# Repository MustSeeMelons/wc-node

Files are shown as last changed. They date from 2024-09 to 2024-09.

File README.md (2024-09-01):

# WC internet radio

Inspired by a restroom that welcomed me as I entered, played smooth jazz while I was inside, and even said goodbye as I left. A Raspberry Pi Zero W at the heart.

All audio playback is based on [this Adafruit article](https://learn.adafruit.com/adafruit-max98357-i2s-class-d-mono-amp/raspberry-pi-wiring).

Legacy 32-bit Pi OS is required for this to work.

## V1

Turns out using a sonar distance sensor for presence detection does not work very well. You might enter the room and stay out of range for a bit, thus triggering a leave. Then after a bit re-trigger it. Many edge cases, for proper operation switch should be on the door and the door must be auto-closing. Otherwise the user experience will be flawed.

Kept the sonar as the on/off switch. Made to just work without spending much time on the looks.

Consists of a Pi Zero W, MAX98357 and a HC-SR04. Everything is powored from the Pi. Suprisingly, sounds better than most laptops.

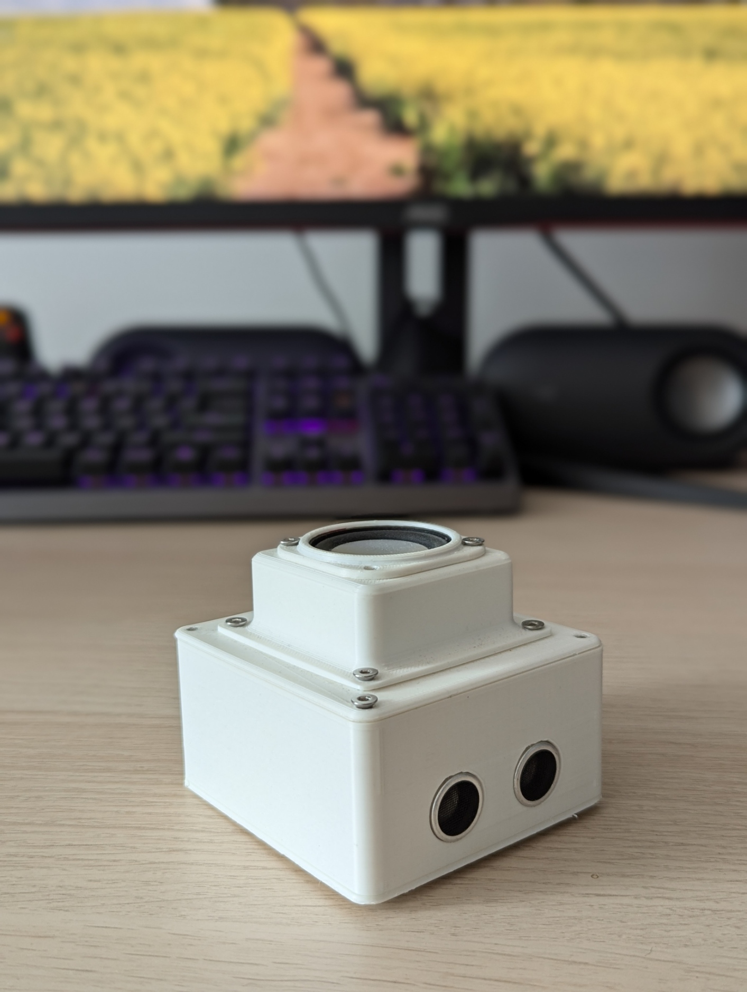
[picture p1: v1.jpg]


## V2

While the V1 worked well, it did not look the part. Also the sonar was a gimmick and it lacked physical volume controls that turned out more important than anticipated.

The sonar was replaced with a switch and a rotary encoder entered the fray. Turn it on/off with the switch and adjust the volume with the ring around the speaker.

Worked well enough, but it sounded worse. Propably because the speaker was not as enclosed as it was previsouly. The ring was also flimsy feeling. For some reason I used a rotary encoder from a mouse. Which is tiny and made positioning it harder. Also bearings would have been nice.

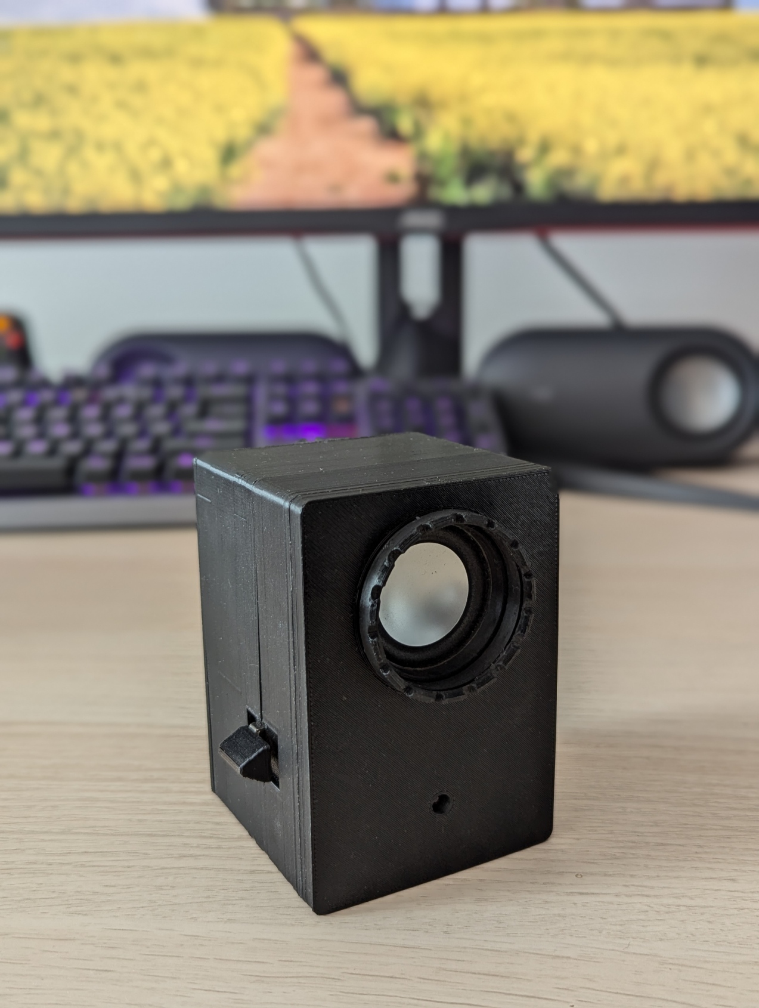
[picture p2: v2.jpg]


## V3

Time to make it louder and make it look even nicer. Made possible by a bunch of interconencted modules: 12V power to an Aliexpress amplifirer. Buck/boost module to step down 12V to 5V for the Pi. An PCM5102A module for turning the Pi's I2S signal into analogue audio. Non removable 12V power brick.

Operation requires pressing a button to turn on audio playback from the Pi and turning nob to turn off the amp and perform volume control.

Sounds better and overall is much more pleasing to the eye.

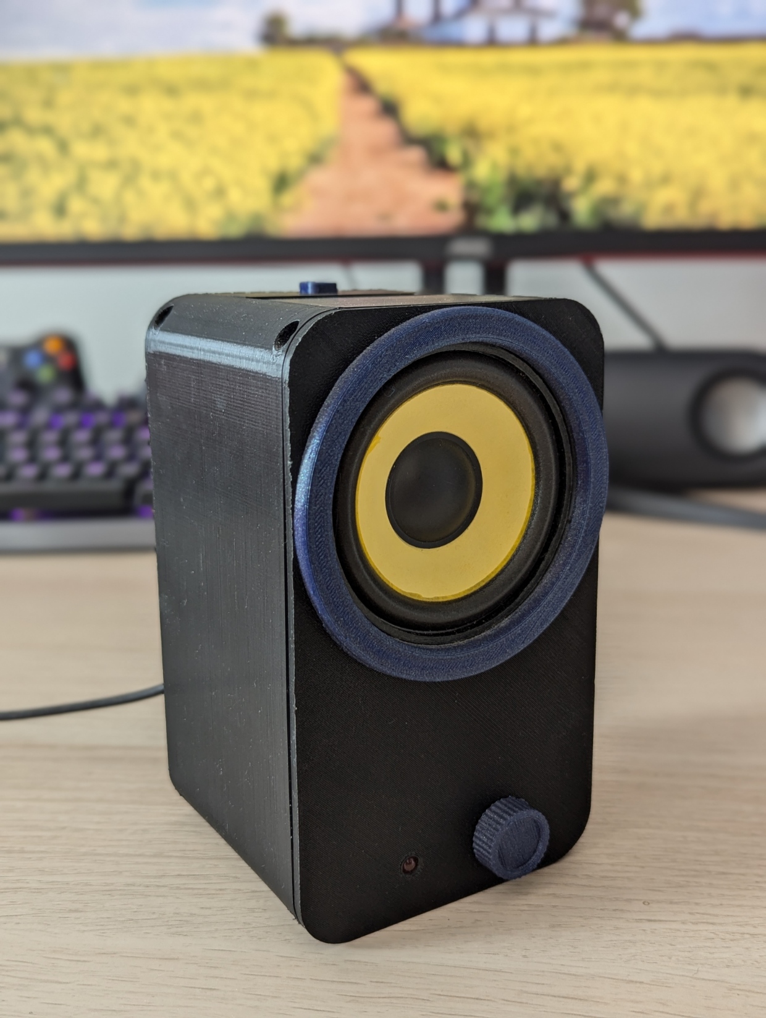
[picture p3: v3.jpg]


## V4

The final iteration: getting rid of the rats nest of modules and making an integrated PCB for all. About 1.5 years of learning electronics made it possible.

It works better as ever and propably is the final form.

Is it perfect? Hell no, but functional without major flaws as far as I know. The PCB layouts ignore `recomended layouts` from the datasheets so to be easier to hand solder.

The speaker size really should be placed into a wooded enclosure. Also the [stream](https://fmstream.org/) quality is a factor now.

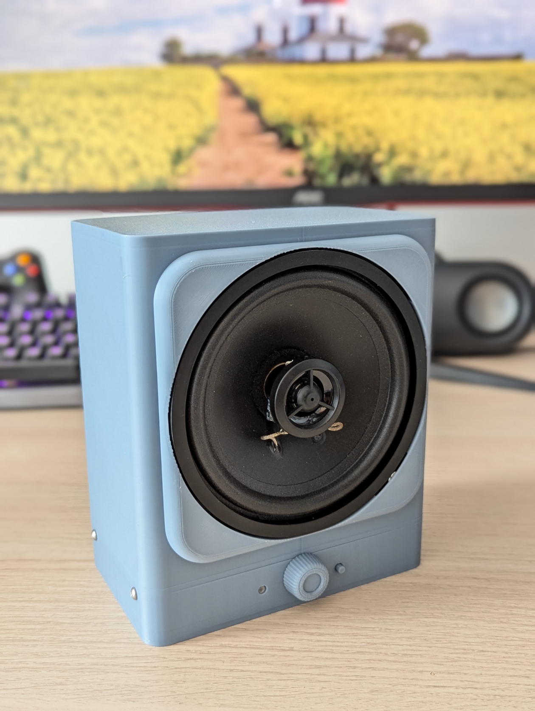
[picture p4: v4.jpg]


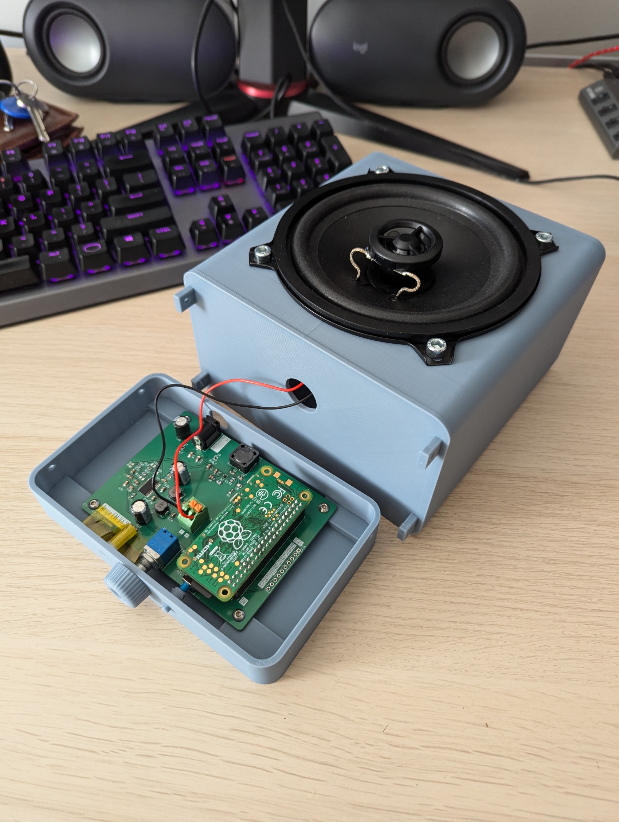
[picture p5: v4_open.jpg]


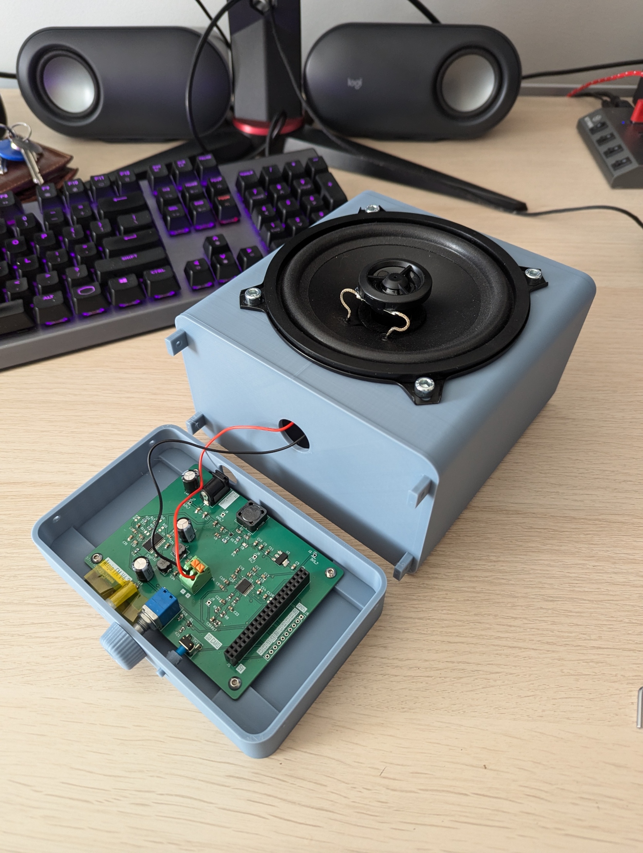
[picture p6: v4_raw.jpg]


# How to

- `sudo apt-get update`
- `npm i`
- `sudo apt-get install -y mpg123`
- `sudo npm start`
- `/etc/systemd/system/ateja.service`

# Node

- `use nvm to install node`
- `sudo ln -s $(which node) /usr/bin/node`
- `sudo ln -s $(which npm) /usr/local/bin/npm`

# A few commands to add to /boot/config.txt

`raspi-gpio set 20 pu`
`raspi-gpio set 4 pu`

# Systemd

- `sudo systemctl daemon-reload`
- `sudo systemctl start ateja`
- `journalctl -u ateja.service -f`
- `sudo systemctl status ateja`
- `sudo systemctl stop ateja`
- `sudo systemctl restart ateja`
- `sudo systemctl enable ateja`
- `sudo systemctl disable ateja`

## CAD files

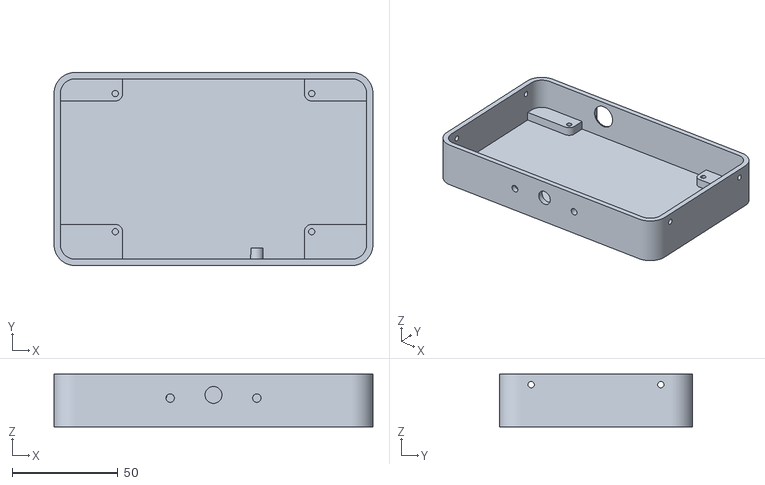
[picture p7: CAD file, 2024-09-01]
cad/stl/Bottom.stl
151.0 x 91.4 x 25.0

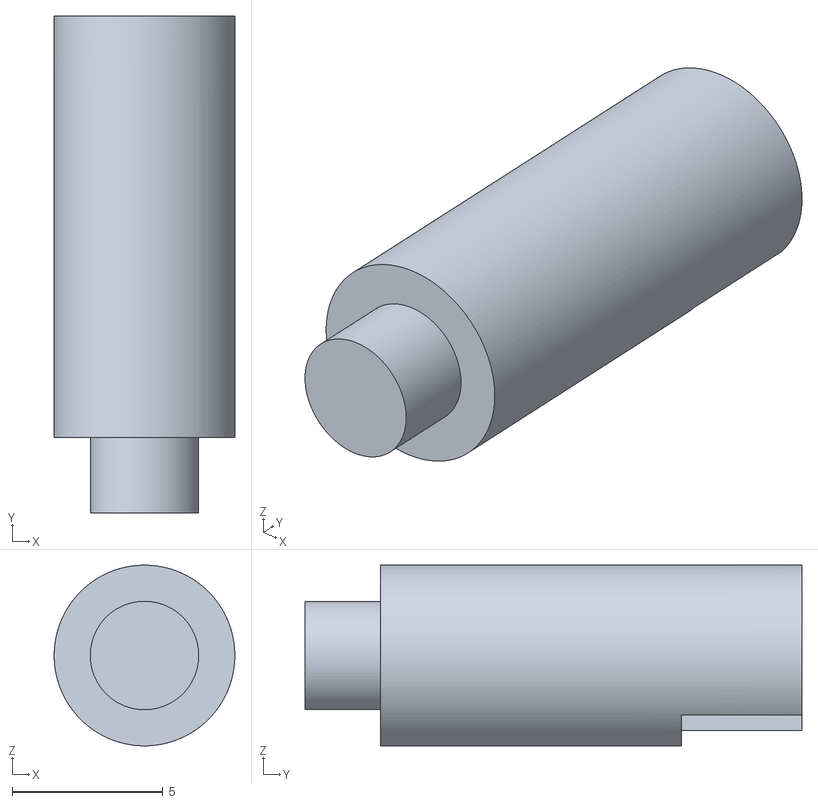
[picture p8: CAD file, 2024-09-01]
cad/stl/LED Thingy.stl
6.00 x 16.5 x 6.00

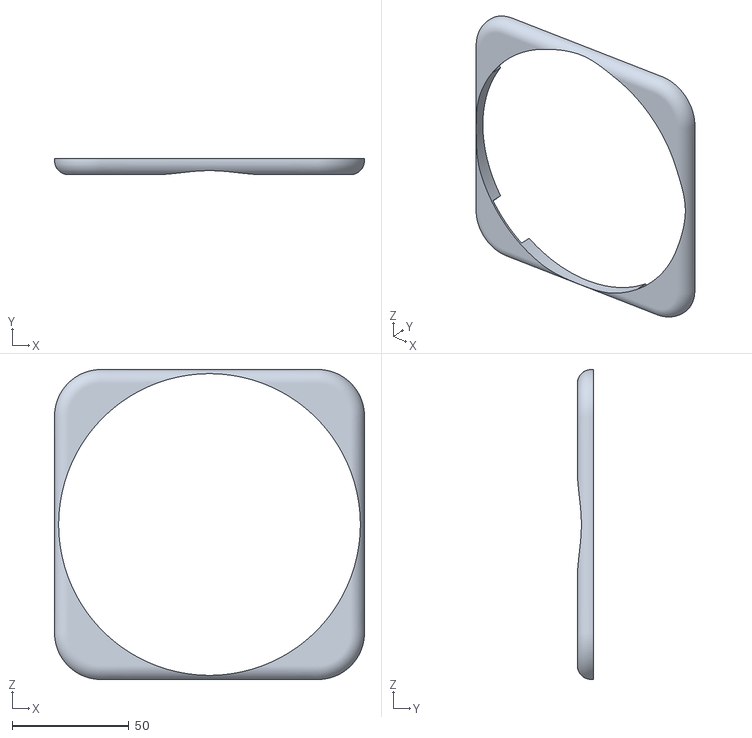
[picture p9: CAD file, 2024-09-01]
cad/stl/Ring.stl
133.0 x 7.00 x 133.0

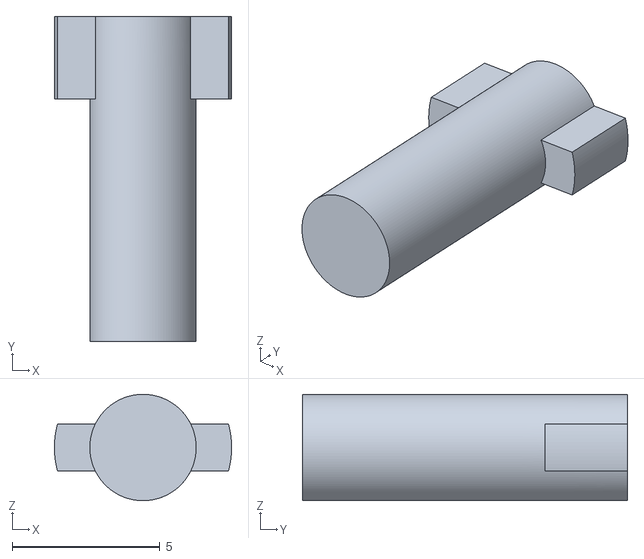
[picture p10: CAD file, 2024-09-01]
cad/stl/Button.stl
6.00 x 11.0 x 3.60

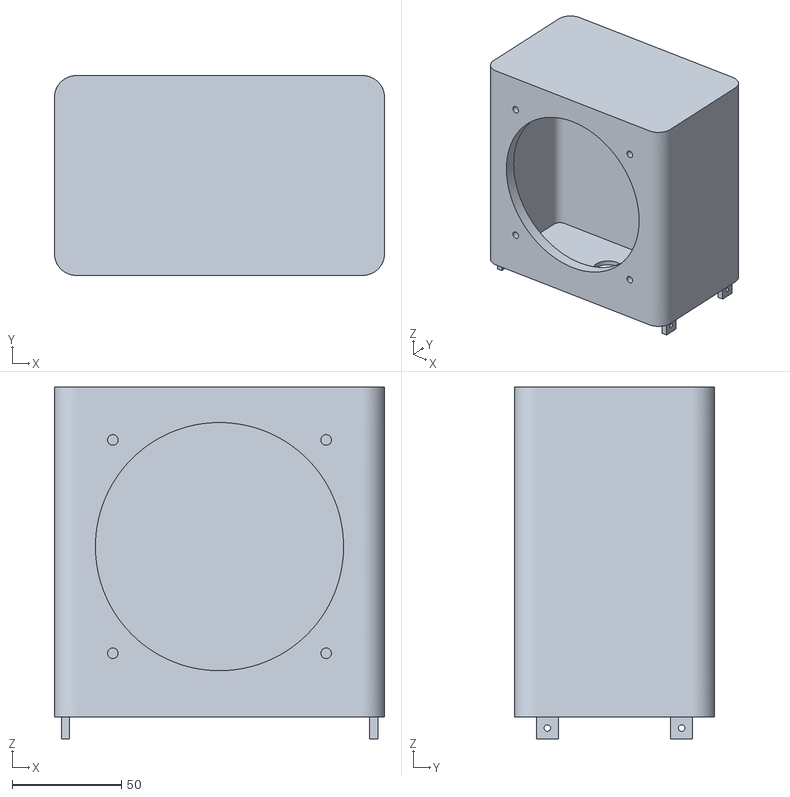
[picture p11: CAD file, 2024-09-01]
cad/stl/Top.stl
151.0 x 91.4 x 161.0

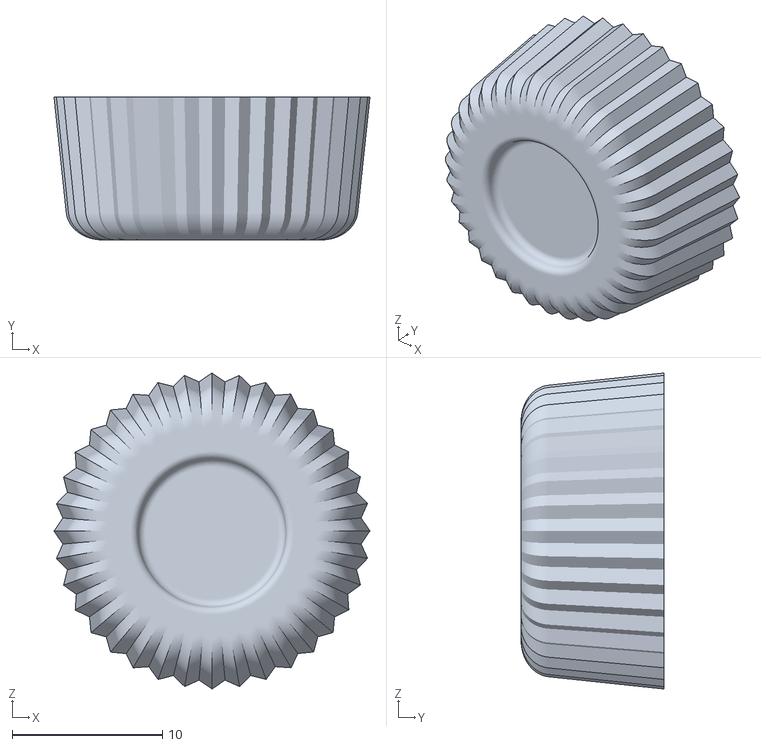
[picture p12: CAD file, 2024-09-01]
cad/stl/Knob.stl
21.0 x 9.50 x 21.0

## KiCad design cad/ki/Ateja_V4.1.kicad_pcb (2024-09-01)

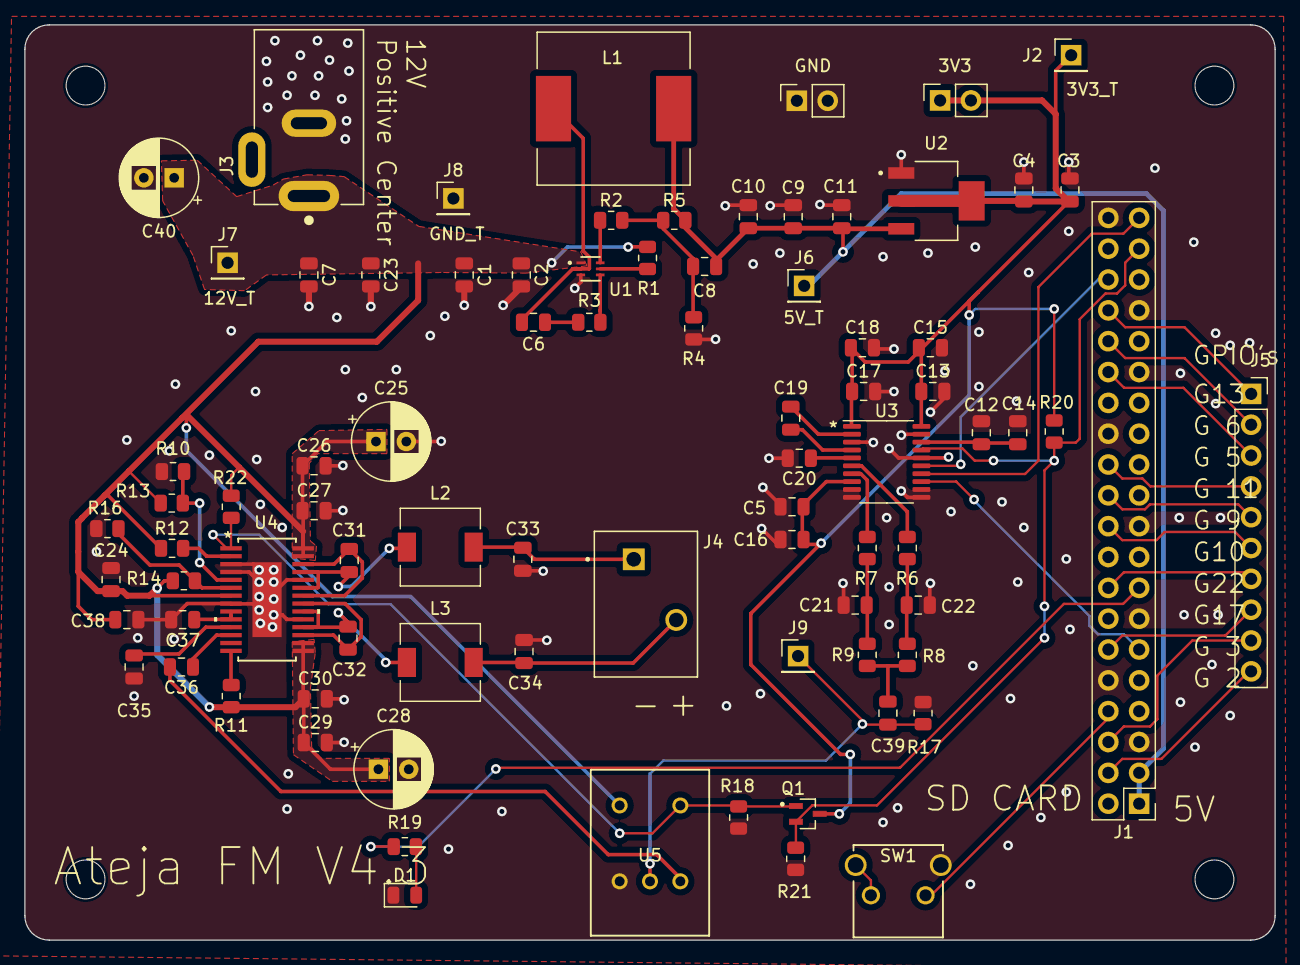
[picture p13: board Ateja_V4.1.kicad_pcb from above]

Board: 2 copper layers, 103.0 x 75.4 mm, 87 parts (0 on the bottom side), 53 nets.

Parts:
C1, C9, C10, C23: 22uF; C_0805_2012Metric
C2, C7: 100 nF; C_0805_2012Metric
C3: 47 uF; C_0805_2012Metric
C4, C11: 1.5 uF; C_0805_2012Metric
C5, C12, C13, C17, C26, C29: 0.1uF; C_0805_2012Metric
C6, C24, C35, C36, C37, C38: 1 uF; C_0805_2012Metric
C8: 10 pF; C_0805_2012Metric
C14, C15, C16, C18, C39: 10 uF; C_0805_2012Metric
C19, C20: 2.2uF; C_0805_2012Metric
C21, C22: 2.2 nF; C_0805_2012Metric
C25, C28: 220 uF; CP_Radial_D6.3mm_P2.50mm
C27, C30: 1000pF; C_0805_2012Metric
C31, C32: 0.47uF; C_0805_2012Metric
C33, C34: 1uF; C_0805_2012Metric
C40: 100 uF; CP_Radial_D6.3mm_P2.50mm
D1: LED; LED_0805_2012Metric
H1, H2, H3, H4: MountingHole; MountingHole_3.2mm_M3
J1: Conn_02x20_Odd_Even; PinHeader_2x20_P2.54mm_Vertical
J2: 3V3_T; PinHeader_1x01_P2.54mm_Vertical
J3: PJ-202AH; CUI_PJ-202AH
J4: TBL002A-350-02GR-2OR; CUI_TBL002A-350-02GR-2OR
J5: Conn_01x10_Socket; PinSocket_1x10_P2.54mm_Vertical
J6: 5V5_T; PinHeader_1x01_P2.54mm_Vertical
J7: 12V_T; PinHeader_1x01_P2.54mm_Vertical
J8: GND_T; PinHeader_1x01_P2.54mm_Vertical
J9: I2S_T; PinHeader_1x01_P2.54mm_Vertical
J10, J11: Conn_01x02_Socket; PinSocket_1x02_P2.54mm_Vertical
L1: 4.7 uH; L_12x12mm_H6mm
L2, L3: 33uH; L_6.3x6.3_H3
Q1: 2N7002W; SOT65P220X100-3N
R1: 100k; R_0805_2012Metric
R2: 18k; R_0805_2012Metric
R3: 10 Ohm; R_0805_2012Metric
R4: 5.49k; R_0805_2012Metric
R5: 40.2k; R_0805_2012Metric
R6, R7, R8, R9, R17: 470 Ohm; R_0805_2012Metric
R10, R14, R20, R22: NC; R_0805_2012Metric
R11, R13, R16: 100K; R_0805_2012Metric
R12: 100k Ohm; R_0805_2012Metric
R18, R21: 1k Ohm; R_0805_2012Metric
R19: 1K; R_0805_2012Metric
SW1: 1825027-8; SW2_1825027-C_TEC
U1: MP1660GTF-Z; SOT563-6PIN_MNP
U2: TLV1117-33CDCYRG3; SOT230P700X180-4N
U3: PCM5102A; TSSOP-20_4.4x6.5mm_P0.65mm
U4: TPA3111D1PWPR; PWP28_6P17X2P4-M
U5: PTR901-2015K-B103; PTR901-2015K-B103_BRN

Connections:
/3V3: C3.1, C4.1, C5.1, C13.1, C15.1, C16.1, C17.1, C18.1, J2.1, J10.1, J10.2, Q1.3, R20.1, U2.2 (OUT), U2.4 (OUT), U3.1 (CPVDD), U3.8 (AVDD), U3.20 (DVDD)
/5V: C8.2, C9.1, C10.1, C11.1, J1.1, J1.3, J6.1, L1.2, R5.2, U2.3 (IN)
/AMP_SD: Q1.1, R18.2, R22.2, U4.1 (*SD), U5.6
/BCK: J1.11, U3.13 (BCK)
/DIN: J1.39, U3.14 (DIN)
/GPIO_2: J1.4, J5.10
/GPIO_3: J1.6, J5.9
/GPIO_5: J1.30, J5.3
/GPIO_6: J1.32, J5.2
/GPIO_9: J1.22, J5.5
/GPIO_10: J1.20, J5.6
/GPIO_11: J1.24, J5.4
/GPIO_13: J1.34, J5.1
/GPIO_17: J1.12, J5.8
/GPIO_22: J1.16, J5.7
/INP: C36.2, U5.3
/LED_ACTIVE: J1.15, R19.2
/LRCK: J1.36, U3.15 (LRCK)
/MUTE_LOW: J1.37, Q1.2, R20.2, R21.2, U3.17 (XSMT)
/POWER_OFF: J1.8, SW1.2
GND: C1.2, C2.2, C3.2, C4.2, C5.2, C7.2, C9.2, C10.2, C11.2, C12.2, C13.2, C14.2, C15.2, C16.2, C17.2, C18.2, C20.2, C21.2, C22.1, C23.2, C24.1, C25.2, C26.2, C27.2, C28.2, C29.2, C30.2, C33.1, C34.2, C35.2, C37.1, C38.2, C40.2, D1.1 (K), J1.5, J1.10, J1.13, J1.19, J1.26, J1.29, J1.33, J1.40, J3.2, J8.1, J11.1, J11.2, R4.1, R10.2, R16.2, R17.1, R18.1, R21.1, SW1.4, U1.3 (GND), U2.1 (ADJ/GND), U3.3 (CPGND), U3.9 (AGND), U3.10 (DEMP), U3.11 (FLT), U3.12 (SCK), U3.16 (FMT), U3.19 (DGND), U4.3 (GND), U4.4 (GND), U4.8 (AGND), U4.19 (PGND), U4.24 (PGND), U4.29 (EPAD), U5.1
unnamed: C6.2, R3.2
unnamed: C8.1, R2.2, R4.2, R5.1
unnamed: C21.1, R7.1, R9.2
unnamed: C22.2, R6.1, R8.2
unnamed: C31.1, U4.22 (BSN), U4.26 (BSN)
unnamed: C31.2, L2.1, U4.23 (OUTN), U4.25 (OUTN)
unnamed: C32.1, U4.17 (BSP), U4.21 (BSP)
unnamed: C32.2, L3.1, U4.18 (OUTP), U4.20 (OUTP)
unnamed: C33.2, J4.1, L2.2
unnamed: C34.1, J4.2, L3.2
unnamed: C39.1, R8.1, R9.1
unnamed: D1.2 (A), R19.1
unnamed: C39.2, J9.1, R17.2, U5.2
unnamed: R11.1, U4.14 (AVCC)
unnamed: SW1.1, SW1.3
unnamed: R3.1, U1.4 (BST)
unnamed: R1.2, U1.5 (EN)
unnamed: R2.1, U1.6 (FB)
unnamed: C6.1, L1.1, U1.2 (SW)
unnamed: C19.2, U3.4 (CAPM)
unnamed: C19.1, U3.2 (CAPP)
unnamed: C12.1, C14.1, U3.18 (LDOO)
unnamed: R6.2, U3.6 (OUTL)
unnamed: R7.2, U3.7 (OUTR)
unnamed: C20.1, U3.5 (VNEG)
unnamed: R12.2, U4.2 (*FAULT)
unnamed: R10.1, R13.1, U4.5 (GAIN0)
unnamed: R14.1, R16.1, U4.6 (GAIN1)
unnamed: C37.2, U4.9 (GVDD), U4.10 (PLIMIT)
unnamed: C35.1, U4.11 (INN)
unnamed: C36.1, U4.12 (INP)
VCC: C1.1, C2.1, C7.1, C23.1, C24.2, C25.1, C26.1, C27.1, C28.1, C29.1, C30.1, C38.1, C40.1, J3.1, J7.1, R1.1, R11.2, R12.1, R13.2, R14.2, R22.1, U1.1 (VIN), U4.7 (AVCC), U4.15 (PVCC), U4.16 (PVCC), U4.27 (PVCC), U4.28 (PVCC), U5.4

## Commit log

2021-03-30 Basic pin setup
2021-03-30 Sonar Test
2021-03-30 Partial Sonar
2021-03-31 Sad Sonar
2021-04-03 Fix LED pin
2021-04-05 Refactor flow, web sound options WIP
2021-04-14 Sonar toggle
2021-04-14 More wait if sonar disabled
2021-04-15 Socket test
2021-05-22 Tweak sonar & LED behavior
2021-07-20 Turn on led before fadeout, a bit moar wait.
    Started to turn off on itself..
2021-07-20 Change next sonar state on api call too
2022-08-03 Removed interrupts
2022-08-26 Alert pwr button test
2022-08-26 Add rotary interrupt, pwr log
2022-09-15 It was a loose wire, removed sonar
2022-09-17 LED pwm
2022-09-23 Remove sonar stuff from script
2024-09-01 Update readme, cleanup old code
    It is done.
    [Ateja_V4.1-B_Cu.gbr, Ateja_V4.1-B_Mask.gbr, Ateja_V4.1-B_Paste.gbr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]
